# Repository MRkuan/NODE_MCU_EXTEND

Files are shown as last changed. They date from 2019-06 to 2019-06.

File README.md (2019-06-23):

# NODE_MCU_EXTEND
node mcu V 1.1 扩展版

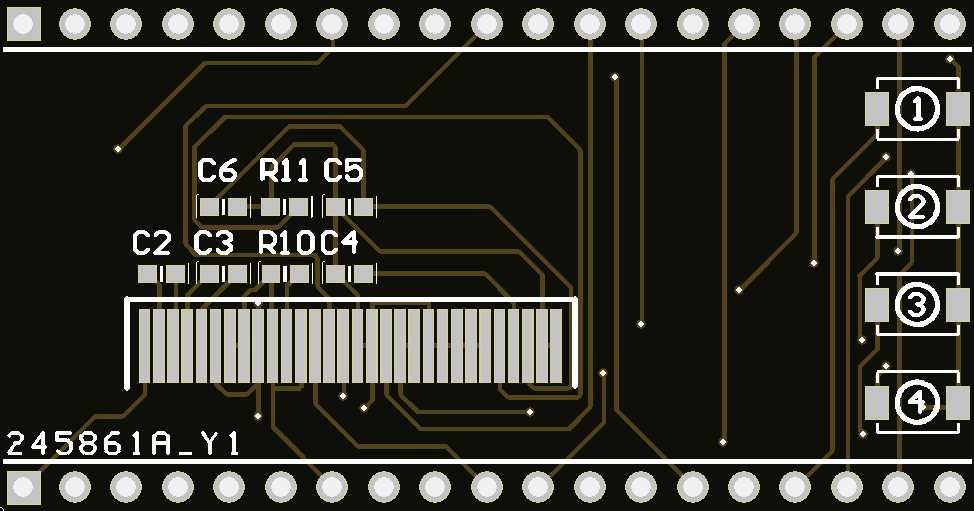
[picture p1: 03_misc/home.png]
home


## 1.整体介绍

NODE_MCU_EXTEND扩展板 是基于 [NODE_MCU](http://www.nodemcu.com/index_cn.html)基于ESP32开发的一款测试开发板，
其效果如下图所示
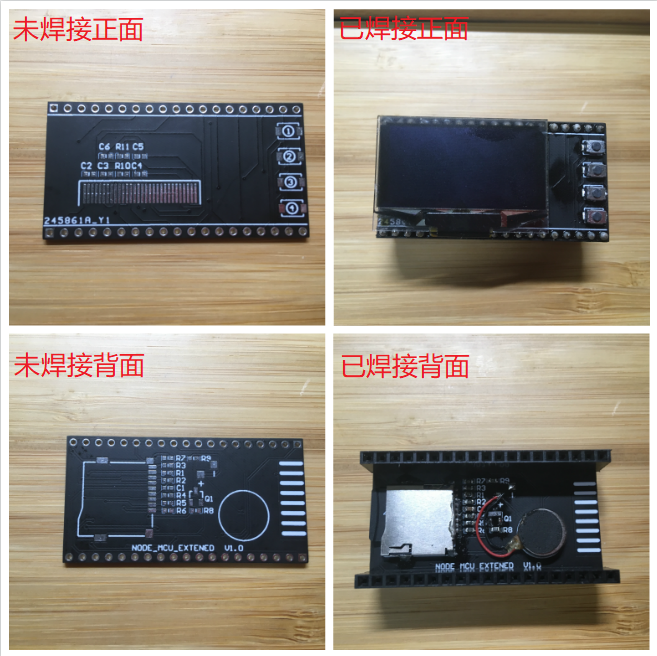
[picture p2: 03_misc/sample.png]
sample
)

原理图

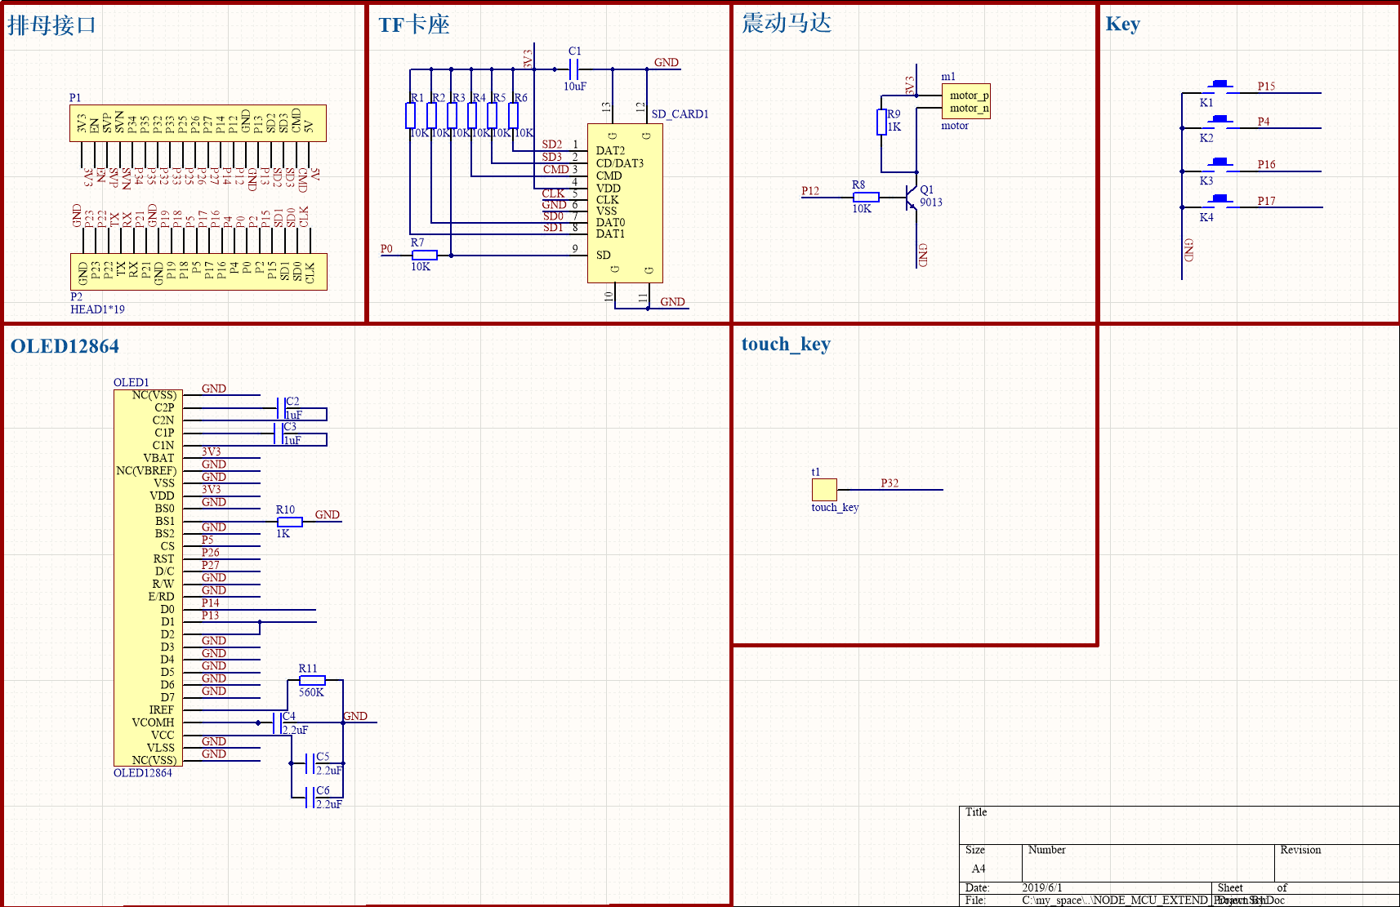
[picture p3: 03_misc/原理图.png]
原理图


包含了4个KEY，1个touchKEY，一个OLED1.3（SSD1306 or SH1106）,一个TF卡和一个震动马达组成。

> PIN 分配图

**SD卡功能作废**
因为官方明确

> 管脚 SCK/CLK， SDO/SD0， SDI/SD1， SHD/SD2， SWP/SD3，和 SCS/CMD，即 GPIO6 至 GPIO11 用于连接模组上
> 集成的 SPI flash，不建议用于其他功能
> 
组件 | PIN |  备注
-|-|-
OLED12864 | - | -
~ | GPIO14 | SPI_CLK
 -| GPIO13| SPI_MOSI
  -| -|MISO可以不接
-| GPIO26|RESET
-| GPIO27|DC
-| GPIO5|CS
TF_CARD(SDIO) | - | -
 -| GPIO6 | CLK
  -| GPIO11 |CMD/DI0
  -| GPIO7|DAT0
-| GPIO8|DAT1
-| GPIO9|DAT2
-| GPIO10|DAT3
-| GPIO0|SD_DET
TF_CARD(SPI) | - | -
-| GPIO10|CS
-| GPIO11|MOSI
-| GPIO6|CLK
-| GPIO7|MISO
key | - | -
 -| GPIO15 | KEY1
  -| GPIO4 |KEY2
-| GPIO16|KEY3
-| GPIO17|KEY4
-| GPIO32|touchkey
motor | - | -
 -| GPIO12 | 使用PWM驱动 频率在 1HZ-10HZ

 ## 2.测试

 本板使用  [esp-wroom-32](https://www.espressif.com/zh-hans/products/hardware/esp-wroom-32/overview)作为核心控制元件,[micropython](http://www.micropython.org/)为主要编程语言

 其中 ESP32 资料[下载地址](https://www.espressif.com/zh-hans/support/download/documents?keys=ESP32),

esp32 micropython [固件地址](http://www.micropython.org/download)

### 2.1 刷micropython 固件

首先需要安装esptool
> pip install esptool

然后确认COM口
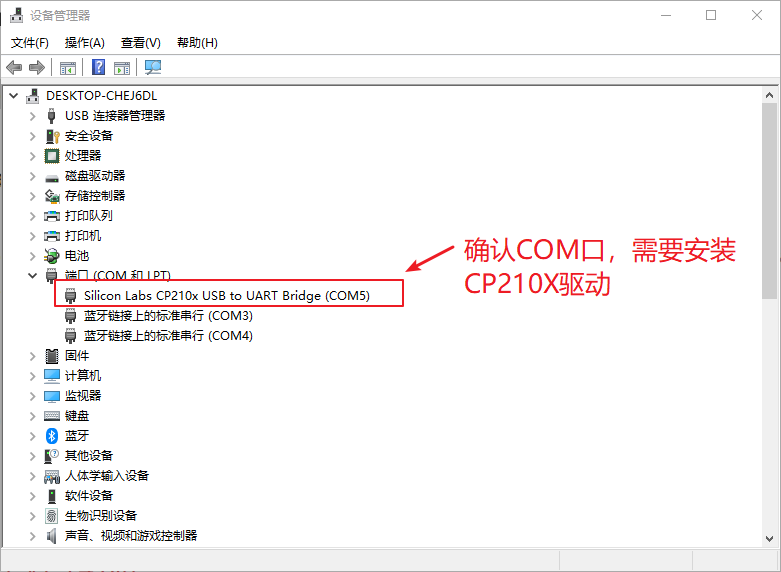
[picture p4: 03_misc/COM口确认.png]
COM口确认


进行擦除FLASH，烧录固件

> esptool.py --chip esp32 --port COM5 erase_flash

> esptool.py --chip esp32 --port COM5 --baud 460800 write_flash -z 0x1000 esp32-20190605-v1.11-37-g62f004ba4.bin

或者

> esptool.py --chip esp32 --port COM5 --baud 460800 write_flash -z 0x1000 esp32spiram-20190606-v1.11-37-g62f004ba4.bin

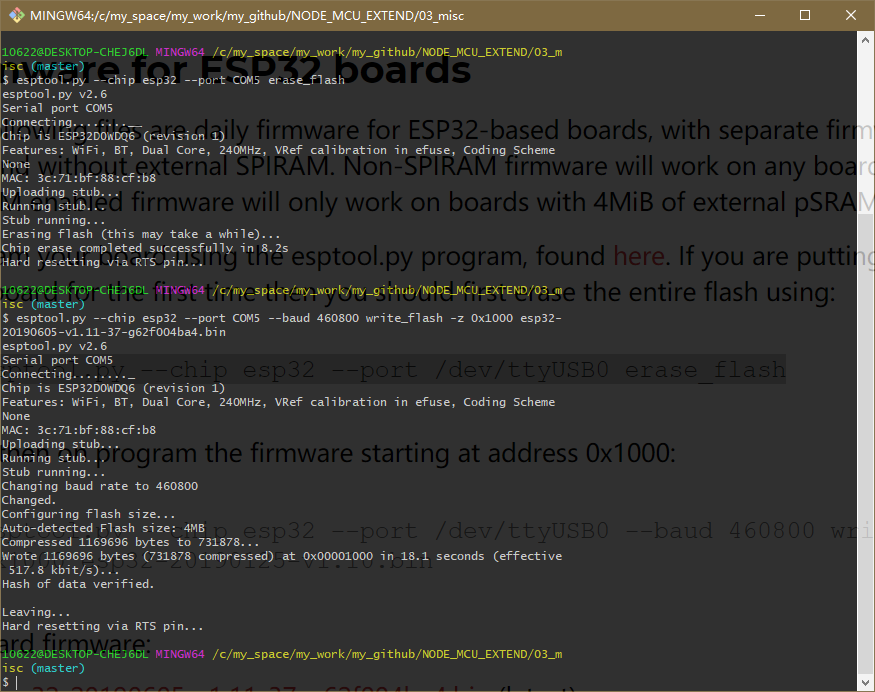
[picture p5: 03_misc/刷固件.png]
刷固件


### 2.2 使用 uPyLoader 同步程序

[uPyLoader](https://github.com/BetaRavener/uPyLoader) 是基于串口的同步软件

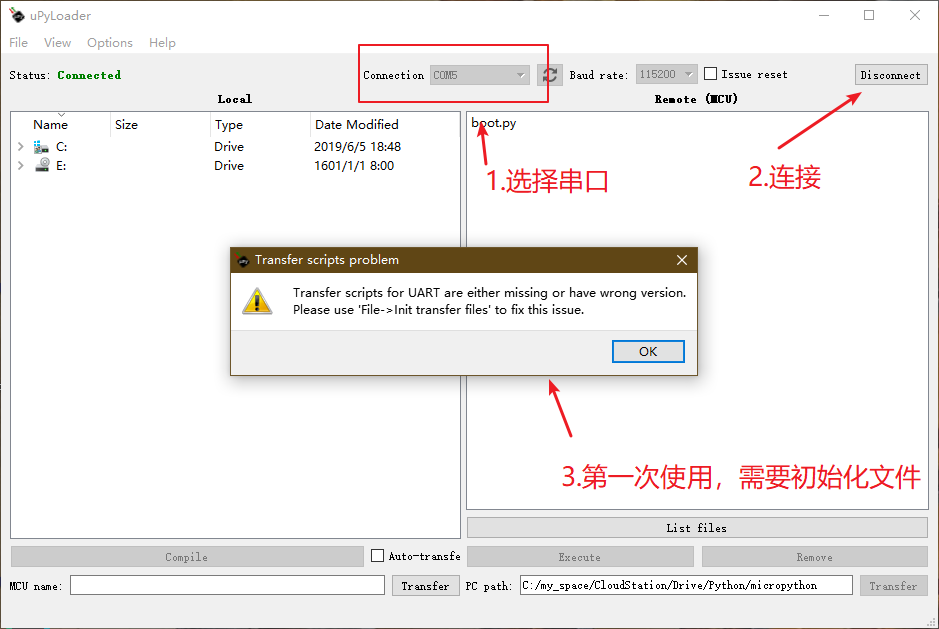
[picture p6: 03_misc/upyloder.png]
uPyLoader


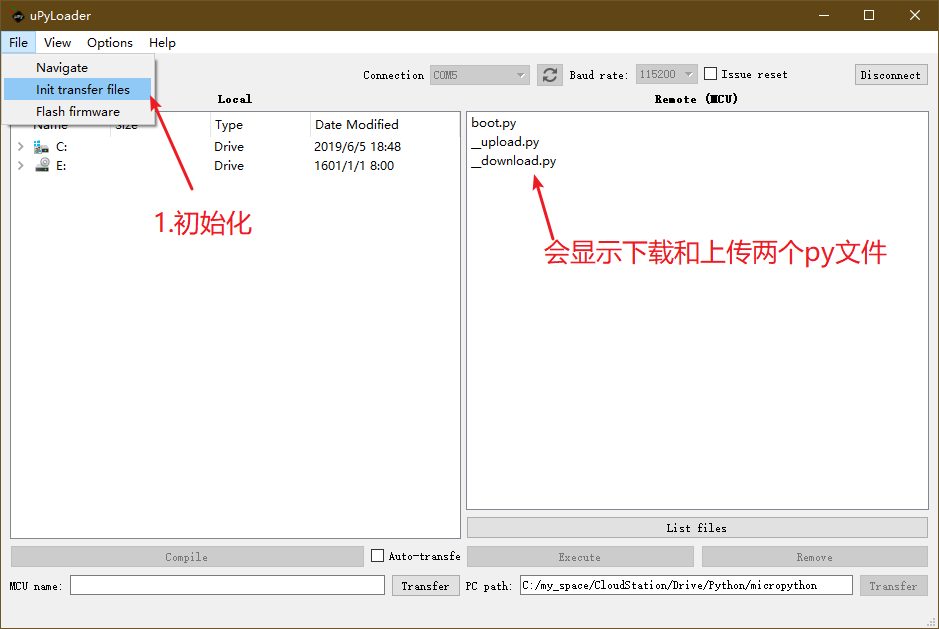
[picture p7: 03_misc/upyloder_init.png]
upyloder_init


## 3.参考
参考地址  |  备注
-|-
[MicroPython入坑记（二）刷固件（ESP8266 ESP32）](https://www.cnblogs.com/yafengabc/p/8681380.html) | 刷micropython固件参考
[micropython](https://github.com/micropython/micropython) | micropython官方地址
[esp32 micropython](http://docs.micropython.org/en/latest/esp32/general.html) | esp32 micropython使用API
[SH1106](https://github.com/robert-hh/SH1106) | SH1106 micropython 固件

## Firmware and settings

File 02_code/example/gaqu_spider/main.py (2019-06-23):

from machine import Pin, SPI
import sh1106
import time
import network
import socket
import node_mcu_extend_key
import node_mcu_extend_spider
import node_mcu_extend_pic
import node_mcu_extend_ring
import _thread
import boot

p12 = Pin(12, Pin.OUT) #close motor
p12.off()

key_all = node_mcu_extend_key.key_class(15,4,16,17,32)
_thread.start_new_thread(key_all.key_thread, ())

spider_all = node_mcu_extend_spider.spider_class()
_thread.start_new_thread(spider_all.gaqu_door_state_thread, ())
_thread.start_new_thread(spider_all.current_hour_min_thread, ())

ring_all = node_mcu_extend_ring.ring_class(12)
_thread.start_new_thread(ring_all.ring_thread, ())

def show_time(hour,min):
	boot.display.fill(0)
	hour_high =  hour//10
	hour_low = hour%10
	min_high = min//10
	min_low =  min%10
	# print(hour_high,hour_low,min_high,min_low)
	boot.display.fill(0)
	boot.display.diplay_pic(12,16,12+16,16+32,node_mcu_extend_pic.num_pic[hour_high])
	boot.display.diplay_pic(12+16+6,16,12+16+16+6,16+32,node_mcu_extend_pic.num_pic[hour_low])
	boot.display.diplay_pic(12+16+16+6+6,16,12+16+16+16+6+6,16+32,node_mcu_extend_pic.point_pic)
	boot.display.diplay_pic(12+16+16+16+6+6+6,16,12+16+16+16+16+6+6+6,16+32,node_mcu_extend_pic.num_pic[min_high])
	boot.display.diplay_pic(12+16+16+16+16+6+6+6+6,16,12+16+16+16+16+16+6+6+6+6,16+32,node_mcu_extend_pic.num_pic[min_low])
	boot.display.show()

def show_door():
	boot.display.fill(0)
	boot.display.diplay_pic(32,0,32+64,64,node_mcu_extend_pic.treadmill_pic)
	boot.display.show()

while True:
	hour,min = spider_all.get_current_hour_min()

	door_state = spider_all.get_door_state()
	print("door_state:",door_state)
	if (1 == door_state) :
		show_door()
		# ring_all.start_ring()
	else:
		show_time(hour,min)
		# ring_all.stop_ring()

	time.sleep(1)
	pass

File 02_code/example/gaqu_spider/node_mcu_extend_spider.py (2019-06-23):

from machine import Pin, TouchPad
from micropython import const
import time
import _thread
import network
import socket
import ssl
current_hour_min_lock = _thread.allocate_lock()
gaqu_door_lock = _thread.allocate_lock()
class spider_class:
	def __init__(self):
		self.__hour = 0
		self.__min  = 0
		self.__door_state  = 0  # 0：规划中 1：空闲 2：在用 3：故障

	def __http_get(self, url):
		_, _, host, path = url.split('/', 3)
		addr = socket.getaddrinfo(host, 80)[0][-1]
		s = socket.socket()
		s.connect(addr)
		s.send(bytes('GET /%s HTTP/1.0\r\nHost: %s\r\n\r\n' % (path, host), 'utf8'))
		data = s.recv(512)
		s.close()
		return str(data, 'utf8')

	def get_current_hour_min(self):
		with current_hour_min_lock:
			val_tuple=(self.__hour,self.__min)
		return val_tuple

	def get_door_state(self):
		with gaqu_door_lock:
			var=self.__door_state
		return var

	def current_hour_min_thread(self):
		while True:
			try:
				str_s = self.__http_get('http://quan.suning.com/getSysTime.do')
				str_search = 'sysTime1'
				if (-1 == str_s.find(str_search)):
						print('no find sysTime1')
				else:
					nPos = str_s.index(str_search) + len('sysTime1') +2
					with current_hour_min_lock:
						self.__hour = int(str_s[nPos+9])*10 + int(str_s[nPos+10])
						self.__min = int(str_s[nPos+11])*10 + int(str_s[nPos+12])
				time.sleep(10)
			except:
				print('get thread time err')

	def gaqu_door_state_thread(self):
		while True:
			try:
				hour,min = self.get_current_hour_min()
				if ((hour>=20)and(hour<=21)):
					s = socket.socket()
					ai = socket.getaddrinfo("rest.ga-qu.com", 443)
					# print("Address infos:", ai)
					addr = ai[0][-1]
					# print("Connect address:", addr)
					s.connect(addr)
					s = ssl.wrap_socket(s)
					s.write(b"POST /api/infoOfCang HTTP/1.1\r\ncharset: utf-8\r\nAccept-Encoding: gzip\r\nreferer: https://servicewechat.com/wxe422d7571f00750b/30/page-frame.html\r\ncontent-type: application/x-www-form-urlencoded\r\nUser-Agent: Mozilla/5.0 (Linux; Android 7.1.2; Redmi Note 5A Build/N2G47H; wv) AppleWebKit/537.36 (KHTML, like Gecko) Version/4.0 Chrome/66.0.3359.158 Mobile Safari/537.36 MicroMessenger/6.7.3.1360(0x26070333) NetType/WIFI Language/zh_CN Process/appbrand0\r\nContent-Length: 48\r\nHost: rest.ga-qu.com\r\nConnection: Keep-Alive\r\n\r\nlongitude=119.415619&latitude=32.37545&range=10000")
					str_s = str(s.read(512), 'utf8')
					s.close()
					str_search = 'cangStatus'
					if (-1 == str_s.find(str_search)):
						print('no find cangStatus')
					else:
						nPos = str_s.index(str_search) + len('cangStatus') +2
						with gaqu_door_lock:
							self.__door_state = int(str_s[nPos])
					time.sleep(5)
				else:
					with gaqu_door_lock:
						self.__door_state = 0
					time.sleep(60)
			except:
				print('get door state err')

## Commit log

2019-05-30 [doc] 初版提交原理图
    [NODE_MCU_EXTEND_Project.PcbDoc, NODE_MCU_EXTEND_Project.PcbLib, NODE_MCU_EXTEND_Project.PrjPcb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]
2019-06-01 [doc] 增加基本PIN脚分布介绍
2019-06-01 [doc] 去除readme.md表格乱码
2019-06-05 [all] 添加测试程序，补充说明
    [code] 增加test key,touchpad,oled,motor
    待增加 TF卡程序
    [README] 增加参考说明，完善使用
2019-06-23 [all] 添加噶趣跑跑爬虫例子去除一些说明
    [add] 添加基于该板子的噶趣跑跑爬虫例子，
    这个例子定时爬虫查询噶趣跑跑门的状态如果是空闲通知到屏幕上
    [update] 更新readme.md SD卡接口和系统冲突，无法解决，推荐硬件SPI，而不是SDIO
